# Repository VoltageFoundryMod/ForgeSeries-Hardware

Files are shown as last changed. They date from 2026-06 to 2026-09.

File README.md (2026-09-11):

# Voltage Foundry Modular

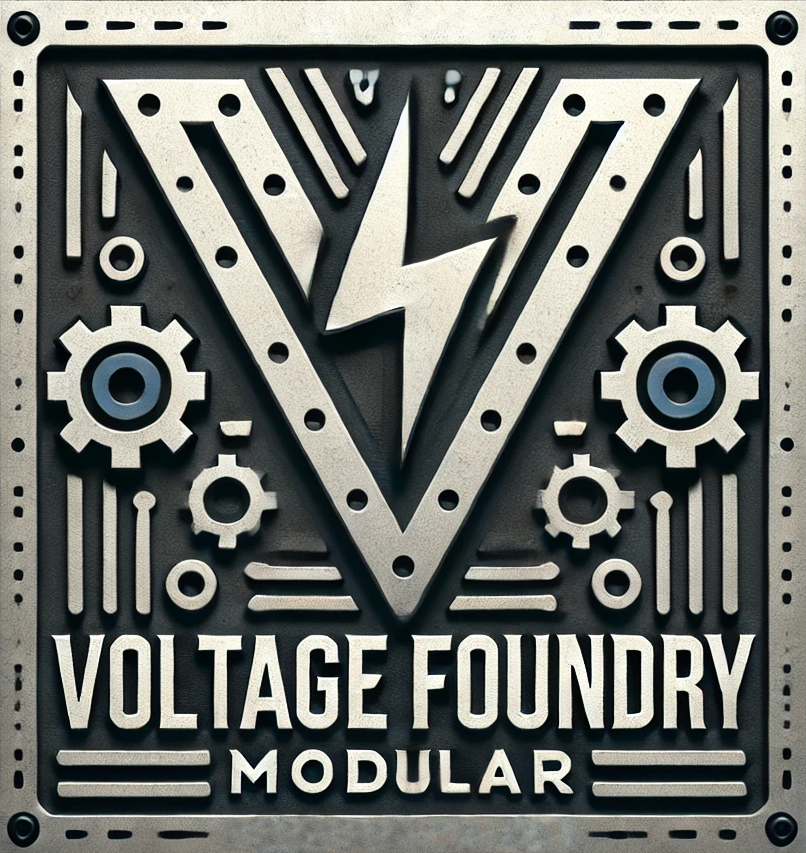
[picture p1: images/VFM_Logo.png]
Voltage Foundry Modular Logo


⚠️ I'm currently finishing a redesign of the hardware and will be ready soon, if you plan to build it, message me thru an issue. 
⚠️

This repository hosts the **Forge** series of modules for the Eurorack format. The **Forge** series is a collection of firmwares developed for the Forge V1 platform based on the Seeeduino Xiao and MCP4725 DAC and Forge V2 hardware based on the Seeeduino Xiao RP2040 anf the MCP4728 DAC.

The modules are designed to be easy to build and modify and be built with through-hole components. The firmware is based on the Arduino platform.

The concept is to have a generic hardware with a display, rotary encoder, trigger inputs and output, CV inputs and outputs allowing different modules by changing the firmware.

This project currently provides the following modules:

- [ClockForge](https://github.com/VoltageFoundryMod/ForgeSeries-CLK/) - A Clock Generator with multiple features like tap tempo, clock division, Euclidean rhythm and more.
- [NoteForge](https://github.com/VoltageFoundryMod/ForgeSeries-DQ/) - A Dual Quantizer with selectable scales and root notes for each channel, octave shift and envelopes.
- [ForgeView](https://github.com/VoltageFoundryMod/ForgeSeries-SCP/) - A scope visualizer with dual-trace, trigger and more.
- [GravityForge](https://github.com/VoltageFoundryMod/ForgeSeries-GEN/) - A generative sequencer with multiple features.

Modules can also be found on ModularGrid:

- [ClockForge](https://modulargrid.net/e/other-unknown-clockforge-by-voltage-foundry-modular)
- [NoteForge](https://modulargrid.net/e/other-unknown-NoteForge-by-voltage-foundry-modular)
- [ForgeView](https://modulargrid.net/e/other-unknown-forgeview-by-voltage-foundry-modular)
- [GravityForge](https://modulargrid.net/e/other-unknown-gravityforge-by-voltage-foundry-modular)

Each new module firmware will be in a separate folder which can be built and uploaded to the Seeeduino Xiao using PlatformIO.

## Production specifications

- Eurorack standard 3U 6HP size
- Power supply: 60mA
- Module depth: 42mm
- On-board converter from 12V to internal 5V

The module can be powered from the MCU USB port while in development mode and from Eurorack 5 pin when in calibration or use. **Do not power from both at the same time as this might damage the module**.

## Project State and Compatibility

- ✅ - Working
- ❎ - Not tested
- 🚧 - Under development
- ❓ - Works with issues

| Firmware | State | Remarks |
| --- | ----- | --- |
| ClockForge | ✅ | V1 HW with 1.x FW, V2 HW with 2.x FW |
| Dual Quantizer | ✅ | Only works on V1 hardware |
| Scope | ❓ | V1 HW, Spectrum Analyzer not working yet |
| Dual Sequencer | 🚧 | |
| Sequencer | ❎ | V1 HW, Original firmware, not tested |
| Generative Sequencer | ❎ | V1 HW, Original firmware, not tested |

## Hardware and PCB

### Hardware V2

### Hardware V1

For the PCBs, the module has one main circuit PCB, one control circuit PCB and one panel PCB. The files are available in the [gerbers](./Hardware/gerbers/) directory. There are files for the main board V1 and V2. The control board and panel are the same for both versions.

Check which Firmware is compatible with which hardware version in the table above before ordering the PCBs, as the main board V2 is only compatible with ClockForge 2.x firmware and not with the other firmwares as of now.

You can order them on any common PCB manufacturing service, I used [JLCPCB](https://jlcpcb.com/).

If the panel size is not correctly detected by JLC manually put 30x128.5 mm.

When ordering the display module, make sure to choose an 0.96 I2C oled module that has the pinout specified as GND-VCC-SCL-SDA as opposed to VCC-GND-SCL-SDA (both exist and the latter won't work).

Check each PCB version BOM for required components.

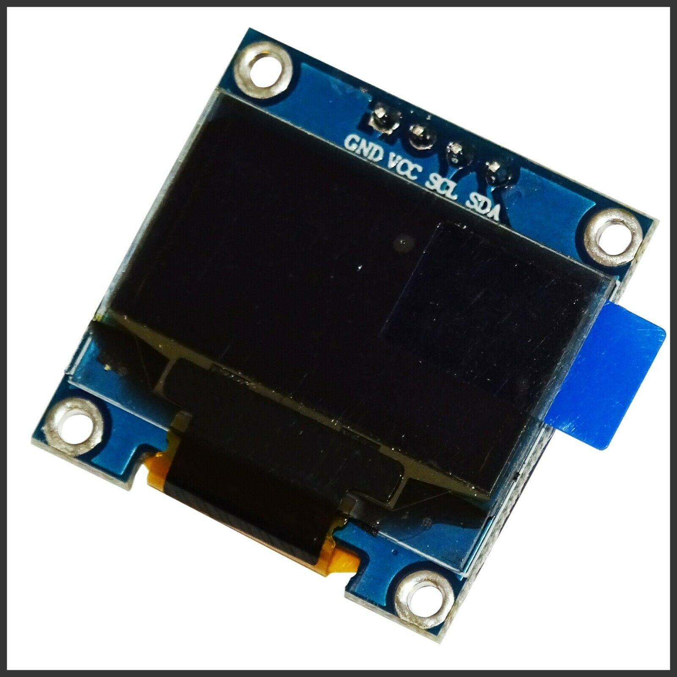
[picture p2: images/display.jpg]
Display Module


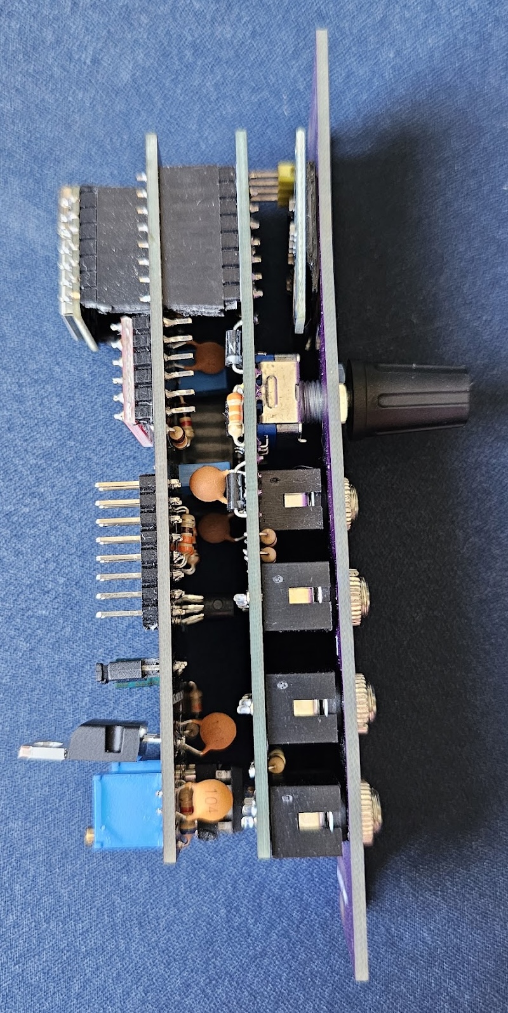
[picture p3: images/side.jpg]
Module Side


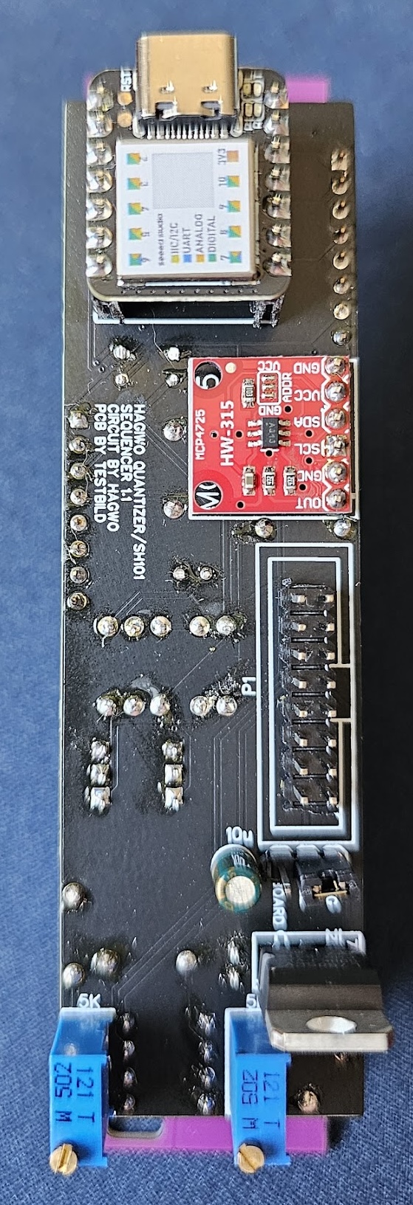
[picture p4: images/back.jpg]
Module Back


Output Diagram:

```text
|--------------------|
|                    |
|         O          |    1
|                    |
|   O           O    |  2   3
|                    |
|                    |
|   O           O    |  4   5
|                    |
|   O           O    |  6   7
|                    |
----------------------
```

- 1 - Trigger / Clock Input
- 2 - CV In 1
- 3 - CV In 2
- 4 - Digital Out 1
- 5 - Digital Out 2
- 6 - Analog Out 1 (Internal DAC)
- 7 - Analog Out 2 (External DAC)

or for the V2 main board:

- 1 - Trigger / Clock Input
- 2 - CV In 1
- 3 - CV In 2
- 4 - Analog Out 1
- 5 - Analog Out 2
- 6 - Analog Out 3
- 7 - Analog Out 4

## Expander header

The V2 main board has a 8 pin header for expanders. The pinout is as follows:

```text
|--------------------|
|                    |
|   1           2    |  VCC(3.3V)   SCL2
|                    |
|   3           4    |  VCC(OPAMP)  SDA2
|                    |
|   5           6    |  -10V(Ref)   GND
|                    |
|   7           8    |  GND         IN4
|                    |
----------------------
```

## Assembly

When assembling, you can either use a header for the screen or solder it directly, as it is a litte too tall.

## Calibration

The V2 board and 2.0 firmware have an internal calibration mode that allows you to set the input compensation and output gain without needing to do the calculations, so it should be easier to calibrate via it's menus. The output calibration still needs to be done by adjusting the trimmers, but the input compensation can be set in the menu and saved to EEPROM.

## Acknowledgements

The initial [hardware](./Hardware/) is based on Hagiwo 033 module. The quantizer base code is from the [original](https://note.com/solder_state/n/nb8b9a2f212a2) Hagiwo 033 Dual Quantizer and the updated thru-hole project by [Testbild-synth](https://github.com/Testbild-synth/HAGIWO-029-033-Eurorack-quantizer). Some ideas for the clock module were "taken" from the [LittleBen module](https://github.com/Quinienl/LittleBen-Firmware) from Quinie.nl and Pamela's Pro Workout.

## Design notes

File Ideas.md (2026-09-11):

# Ideas

Some ideas for projects, features, or improvements that could be implemented in the future. This document serves as a brainstorming space for potential enhancements and innovations.

- Create an output expander (Expander1) adding 4 more analog outputs with it's own DAC and OpAmp using the same I2C bus but on a different address. This would allow for a total of 6 analog outputs on the V2 board. Also expose the fourth ADC input on this board.
- Create an input expander (Expander2) allowing the user to have 8 inputs with an I2C ADC (define if that would be 4 potentiometers and 4 CV inputs or 8 CV inputs or a mix of those). This would allow for a total of 8 inputs on the V2 board. This would allow a more hands-on control to the modules.

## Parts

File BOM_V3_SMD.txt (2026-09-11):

Bill of Materials (BOM) for THT Components:

On Main Board:

1x Seeedstudio XIAO RP2040
2x 1x8 pin header for board interconnection
1x 2x5 pin header for power input
1x 2x4 pin header for expander module
2x 1x7 pin socket for Seeed Xiao board
4x 2k Vishay T93YA/Bourns 3296W vertical trimmer

Control Board:

1x Alps EC11 Rotary Encoder with push switch
2x 1x8 pin socket for board interconnection
7x Thonkiconn 3.5mm Jack
1x SSD1306 0.96" I2C OLED display module (with GND-VCC-SCL-SDA pinout)
4x 2mm Red LED
4x 470R 1/8w resistor
4x 39k 1/8 resistor
4x 10k 1/8 resistor
1x MCP6004 IC in DIP-14 package
1x 10u MLCC Ceramic Capacitor
1x 100n MLCC Ceramic Capacitor

Expander 1:

5x Thonkiconn 3.5mm Jack
1x 2x4 pin header for expander module
4x 2mm Red LED
4x 2k Vishay T93YA/Bourns 3296W vertical trimmer

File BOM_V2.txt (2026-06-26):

Bill of Materials (BOM):

On Main Board:

1x Seeedstudio XIAO RP2040
3x 100n Capacitor ceramic disc
3x 10u 25V Capacitor electrolytic radial
1x MCP4758 on breakout board (<https://pt.aliexpress.com/item/1005007635284632.html>)
1x Zener Diode 1N4734A
5x 470R Resistor
4x 6k8 Resistor
4x 10k Resistor
4x 5k adjustable trimmer (multi turn vertical)
1x MCP6004 DIP-14 op-amp
1x DIP-14 socket
1x 7805 Regulator TO-220

1x 3 pin header with Jumper for DAC power selection
2x 1x8 pin header and socket for board interconnection
1x 2x5 pin header for power input
1x 2x4 pin header for expander module
2x 1x7 pin socket for Seeed Xiao board

Control Board:

2x Resistor 330R
2x Resistor 470R or 2 Jumpers (resistor legs). See Obs below.
2x Resistor 3.3K
2x Resistor 18K
3x Resistor 33K
4x 10n Capacitor ceramic disc
6x BAT43 Diode
1x Alps EC11 Rotary Encoder with push switch
7x Thonkiconn 3.5mm Jack
1x SSD1306 0.96" I2C OLED display module (with GND-VCC-SCL-SDA pinout)

Common:

1x 3 pin header with Jumper for power selection
2x 1x8 pin header and socket for board interconnection
1x 2x8 pin header for power input
2x 1x7 pin socket for Seeed Xiao board

Obs for Main Boards V2:
If reusing existing control boards, replace the two 470R resistors (R13 and R20, close to bottom jacks) with a jumper as the new main board already includes them.
If building new control boards, just use a jumper wire in place of these two resistors.

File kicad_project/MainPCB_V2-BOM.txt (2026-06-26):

Bill of Materials (BOM):

2x 100n Capacitor ceramic disc
1x 10u 25V Capacitor electrolytic radial
1x MCP4758 on breakout board (<https://pt.aliexpress.com/item/1005007635284632.html>)
4x 470R Resistor
4x 6k8 Resistor
4x 10k Resistor
4x 5k adjustable trimmer (multi turn vertical)
1x MCP6004 DIP-14 op-amp
1x DIP-14 socket
1x 7805 Regulator TO-220

1x 3 pin header with Jumper for power selection
2x 1x8 pin header and socket for board interconnection
1x 2x8 pin header for power input
2x 1x7 pin socket for Seeed Xiao board

If using existing front (control) boards, replace the two 470R resistors (R13 and R20, close to bottom jacks) with a jumper as this new board already includes them.

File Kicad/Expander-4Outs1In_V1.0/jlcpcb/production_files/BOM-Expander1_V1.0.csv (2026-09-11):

Comment | Designator | Footprint | LCSC | Quantity
100 | R22 | R_0603 | C22775 | 1
100k | R20,R26,R28,R30,R32 | R_0603 | C25803 | 5
100n | C3,C4,C6 | C_0603 | C14663 | 3
100p | C15 | C_0603 | C14858 | 1
10k | R11,R13,R3,R5 | R_0603 | C25804 | 4
10u | C2,C5 | C_0805 | C15850 | 2
1n | C16 | C_0603 | C1588 | 1
200k | R19 | R_0603 | C25811 | 1
330 | R27,R29,R31,R33 | R_0603 | C23138 | 4
33k | R21 | R_0603 | C4216 | 1
33p | C18,C19,C20,C21 | C_0603 | C1663 | 4
470 | R10,R17,R18,R9 | R_0603 | C23179 | 4
6k8 | R12,R14,R4,R6 | R_0603 | C23212 | 4
9.1k | R15,R16,R7,R8 | R_0603 | C23260 | 4
BC847 | Q2,Q3,Q4,Q5 | SOT-23 | C8664 | 4
MCP4728A1 | U5 | MSOP-10_3x3mm_P0.5mm | C627342 | 1
MCP6001-OT | U2 | SOT-23-5 | C116490 | 1
MCP6004 | U1 | SOIC-14_3.9x8.7mm_P1.27mm | C7378 | 1

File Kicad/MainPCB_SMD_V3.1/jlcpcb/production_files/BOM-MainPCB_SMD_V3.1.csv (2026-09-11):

Comment | Designator | Footprint | LCSC | Quantity
1.5k | R17 | R_0805_2012Metric | C4310 | 1
100k | R18,R20,R22,R27 | R_0603 | C25803 | 4
100n | C1,C14,C15,C29,C3,C6,C9 | C_0603 | C14663 | 7
100p | C26,C27,C28 | C_0603 | C14858 | 3
10k | R1,R3,R5,R7 | R_0603 | C25804 | 4
10n | C30,C31 | C_0603 | C57112 | 2
10u | C13,C5 | C_0805 | C15850 | 2
10u | C12,C2,C4,C7,C8 | CP_Elec_4x5.4 | C3343 | 5
10uF | C25 | C_0603_1608Metric | C96446 | 1
1N4148WS | D1 | D_SOD-323 | C2128 | 1
1N5819WS | D6,D7 | D_SOD-323 | C191023 | 2
1n | C22,C23,C24 | C_0603 | C1588 | 3
2.2u | C17 | CP_Elec_4x5.4 | C43242 | 1
200k | R19,R21,R24 | R_0603 | C25811 | 3
220n | C10,C11,C16 | C_0603 | C21120 | 3
3.3k | R31,R32 | R_0603 | C22978 | 2
33k | R28,R29,R30 | R_0603 | C4216 | 3
33p | C18,C19,C20,C21 | C_0603 | C1663 | 4
4.7k | R23,R25,R26 | R_0603 | C23162 | 3
470 | R10,R11,R12,R9 | R_0603 | C23179 | 4
6k8 | R2,R4,R6,R8 | R_0603 | C23212 | 4
9.1k | R13,R14,R15,R16 | R_0603 | C23260 | 4
FerriteBead | FB1,FB2 | L_0805_2012Metric | C1015 | 2
L78L05 | U4 | SOT89-3 | C42738 | 1
L78M05CDT | U2 | TO-252-2 | C58069 | 1
LM4040LP-10 | U3 | SOT-23 | C201738 | 1
MCP1700x-300xxTT | U6 | SOT-23 | C39051 | 1
MCP4728A0 | U5 | MSOP-10_3x3mm_P0.5mm | C627341 | 1
MCP6004 | U1,U7 | SOIC-14_3.9x8.7mm_P1.27mm | C7378 | 2

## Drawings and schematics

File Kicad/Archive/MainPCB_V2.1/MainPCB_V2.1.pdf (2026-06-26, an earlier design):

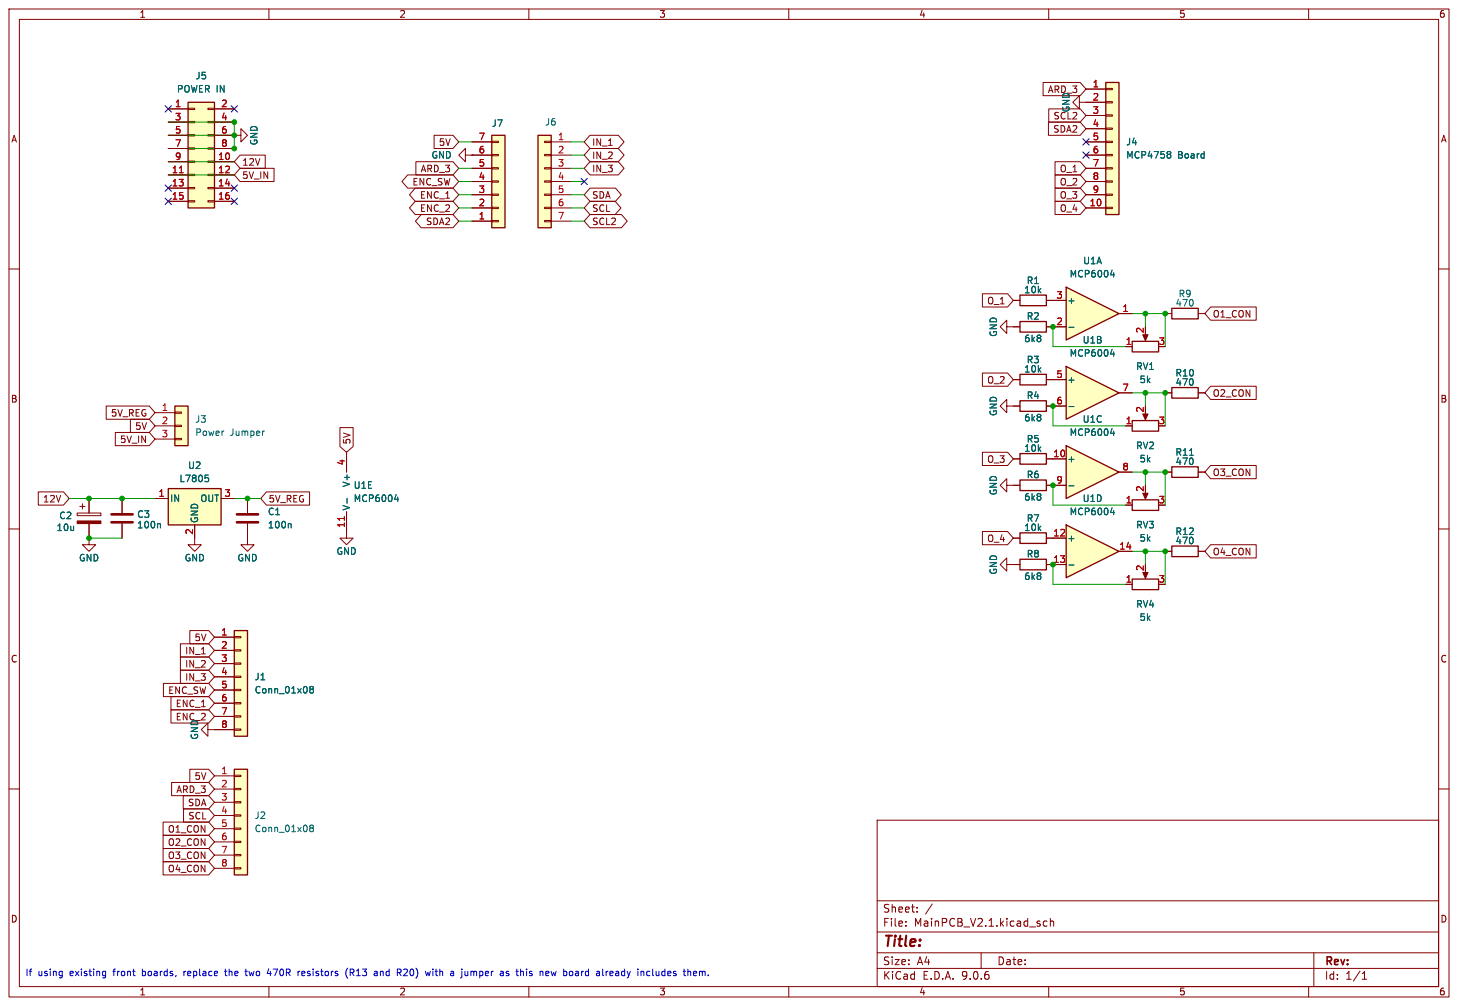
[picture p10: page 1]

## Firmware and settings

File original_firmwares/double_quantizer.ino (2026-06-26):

#include <FlashAsEEPROM_SAMD.h>//flash memory use as eeprom
//Display setting
#include <Adafruit_SSD1306.h>
#include <Adafruit_GFX.h>
#define OLED_ADDRESS 0x3C
#define SCREEN_WIDTH 128
#define SCREEN_HEIGHT 64
Adafruit_SSD1306 display(SCREEN_WIDTH, SCREEN_HEIGHT, &Wire, -1);
#include <Wire.h>
//Rotery encoder setting
#define  ENCODER_OPTIMIZE_INTERRUPTS //counter measure of noise
#include <Encoder.h>


#define ENC_PIN_1 3 //rotary encoder left pin
#define ENC_PIN_2 6 //rotary encoder right pin
#define CLK_PIN 7 //Clock input pin
#define CV_1_IN_PIN 8 // channel 1 analog in
#define CV_2_IN_PIN 9 // channel 2 analog in
#define ENC_CLICK_PIN 10 //pin for encoder switch
#define ENV_OUT_PIN_1 1
#define ENV_OUT_PIN_2 2

////////////////////////////////////////////
// ADC calibration. Change these according to your resistor values to make readings more accurate
float AD_CH1_calb = 0.98;//reduce resistance error
float AD_CH2_calb = 0.98;//reduce resistance error
/////////////////////////////////////////


Encoder myEnc(ENC_PIN_1, ENC_PIN_2);//rotery encoder library setting
float oldPosition  = -999;//rotery encoder library setting
float newPosition = -999;//rotery encoder library setting
int i = 1;

bool SW = 0;
bool old_SW = 0;
bool CLK_in = 0;
bool old_CLK_in = 0;
byte mode = 0; //0=select,1=atk1,2=dcy1,3=atk2,4=dcy2

float AD_CH1, old_AD_CH1, AD_CH2, old_AD_CH2;


int CV_in1, CV_in2;
float CV_out1, CV_out2, old_CV_out1, old_CV_out2;
long gate_timer1, gate_timer2; //EG curve progress speed

int cmp1, cmp2; //Detect closest note
int k = 0;

//envelope curve setting
int ad[200] = {//envelope table
 0, 15, 30, 44, 59, 73, 87, 101,  116,  130,  143,  157,  170,  183,  195,  208,  220,  233,  245,  257,  267,  279,  290,  302,  313,  324,  335,  346,  355,  366,  376,  386,  397,  405,  415,  425,  434,  443,  452,  462,  470,  479,  488,  495,  504,  513,  520,  528,  536,  544,  552,  559,  567,  573,  581,  589,  595,  602,  609,  616,  622,  629,  635,  642,  648,  654,  660,  666,  672,  677,  683,  689,  695,  700,  706,  711,  717,  722,  726,  732,  736,  741,  746,  751,  756,  760,  765,  770,  774,  778,  783,  787,  791,  796,  799,  803,  808,  811,  815,  818,  823,  826,  830,  834,  837,  840,  845,  848,  851,  854,  858,  861,  864,  866,  869,  873,  876,  879,  881,  885,  887,  890,  893,  896,  898,  901,  903,  906,  909,  911,  913,  916,  918,  920,  923,  925,  927,  929,  931,  933,  936,  938,  940,  942,  944,  946,  948,  950,  952,  954,  955,  957,  960,  961,  963,  965,  966,  968,  969,  971,  973,  975,  976,  977,  979,  980,  981,  983,  984,  986,  988,  989,  990,  991,  993,  994,  995,  996,  997,  999,  1000, 1002, 1003, 1004, 1005, 1006, 1007, 1008, 1009, 1010, 1012, 1013, 1014, 1014, 1015, 1016, 1017, 1018, 1019, 1020
};
int ad1 = 0;//PWM DUTY reference
int ad2 = 0;//PWM DUTY reference
bool ad_trg1 = 0;
bool ad_trg2 = 0;
int atk1, atk2, dcy1, dcy2; //attack time,decay time
bool sync1, sync2; //0=sync with trig , 1=sync with note change
int sensitivity_ch1, sensitivity_ch2, oct1, oct2; //sens = AD input attn,amp.oct=octave shift

//CV setting
int cv_qnt_thr_buf1[62];//input quantize
int cv_qnt_thr_buf2[62];//input quantize
byte search_qnt = 0;
bool note1[12];//1=note valid,0=note invalid
bool note2[12];
byte note_str1, note_str11, note_str2, note_str22;

//display
bool disp_reflesh = 1;//0=not reflesh display , 1= reflesh display , countermeasure of display reflesh bussy

//-------------------------------Initial setting--------------------------
void setup() {
 analogWriteResolution(10);
 analogReadResolution(12);
 pinMode(CLK_PIN, INPUT_PULLDOWN); //CLK in
 pinMode(CV_1_IN_PIN, INPUT);//IN1
 pinMode(CV_2_IN_PIN, INPUT);//IN2
 pinMode(ENC_CLICK_PIN, INPUT_PULLUP);//push sw
 pinMode(ENV_OUT_PIN_1, OUTPUT); //CH1 EG out
 pinMode(ENV_OUT_PIN_2, OUTPUT); //CH2 EG out
 // OLED initialize
 display.begin(SSD1306_SWITCHCAPVCC, 0x3C);
 display.clearDisplay();

 //I2C connect
 Wire.begin();

 // ADC settings. These increase ADC reading stability but at the cost of cycle time. Takes around 0.7ms for one reading with these
 REG_ADC_AVGCTRL |= ADC_AVGCTRL_SAMPLENUM_1;
 ADC->AVGCTRL.reg = ADC_AVGCTRL_SAMPLENUM_128 | ADC_AVGCTRL_ADJRES(4);


 //read stored data
 if (EEPROM.isValid() == 1) { //already writed eeprom
   note_str1 = EEPROM.read(1);
   note_str11 = EEPROM.read(2);
   note_str2 = EEPROM.read(3);
   note_str22 = EEPROM.read(4);
   atk1 = EEPROM.read(5);
   dcy1 = EEPROM.read(6);
   atk2 = EEPROM.read(7);
   dcy2 = EEPROM.read(8);
   sync1 = EEPROM.read(9);
   sync2 = EEPROM.read(10);
   oct1 = EEPROM.read(11);
   oct2 = EEPROM.read(12);
   sensitivity_ch1 = EEPROM.read(13);
   sensitivity_ch2 = EEPROM.read(14);
 }
 else if ( EEPROM.isValid() == 0) { //no eeprom data , setting any number to eeprom
   note_str1 = 0;
   note_str11 = 0;
   note_str2 = 2;
   note_str22 = 2;
   atk1 = 1;
   dcy1 = 4;
   atk2 = 2;
   dcy2 = 6;
   sync1 = 1;
   sync2 = 1;
   oct1 = 2;
   oct2 = 2;
   sensitivity_ch1 = 4;
   sensitivity_ch2 = 4;
 }
 //setting stored note data
 for ( int j = 0; j <= 7 ; j++ ) {
   note1[j] = bitRead(note_str1, j);
   note2[j] = bitRead(note_str2, j);
 }
 for ( int j = 0; j <= 3 ; j++ ) {
   note1[j + 8] = bitRead(note_str11, j);
   note2[j + 8] = bitRead(note_str22, j);
 }

 //initial quantizer setting
 k = 0;
 for (byte j = 0; j <= 62; j++) {
   if (note1[j % 12] == 1) {
     cv_qnt_thr_buf1[k] = 17 * j - 8;
     k++;
   }
 }
 k = 0;
 for (byte j = 0; j <= 62; j++) {
   if (note2[j % 12] == 1) {
     cv_qnt_thr_buf2[k] = 17 * j - 8;
     k++;
   }
 }
}

void loop() {
 old_SW = SW;
 old_CLK_in = CLK_in;
 old_CV_out1 = CV_out1;
 old_CV_out2 = CV_out2;
 old_AD_CH1 = AD_CH1;
 old_AD_CH2 = AD_CH2;

 //-------------------------------Rotery endoder--------------------------
 newPosition = myEnc.read();
 if ( (newPosition - 3) / 4  > oldPosition / 4) { //4 is resolution of encoder
   oldPosition = newPosition;
   disp_reflesh = 1;
   switch (mode) {
     case 0:
       i = i - 1;
       if (i < 0) {
         i = 34;
       }
       break;
     case 1:
       atk1--;
       break;
     case 2:
       dcy1--;
       break;
     case 3:
       atk2--;
       break;
     case 4:
       dcy2--;
       break;
   }
 }
 else if ( (newPosition + 3) / 4  < oldPosition / 4 ) { //4 is resolution of encoder
   oldPosition = newPosition;
   disp_reflesh = 1;
   switch (mode) {
     case 0:
       i = i + 1;
       if (34 < i) {
         i = 0;
       }
       break;
     case 1:
       atk1++;
       break;
     case 2:
       dcy1++;
       break;
     case 3:
       atk2++;
       break;
     case 4:
       dcy2++;
       break;
   }
 }
 i = constrain(i, 0, 34);
 atk1 = constrain(atk1, 1, 26);
 dcy1 = constrain(dcy1, 1, 26);
 atk2 = constrain(atk2, 1, 26);
 atk2 = constrain(atk2, 1, 26);
 dcy2 = constrain(dcy2, 1, 26);

 //-----------------PUSH SW------------------------------------
 SW = digitalRead(ENC_CLICK_PIN);
 if (SW == 1 && old_SW != 1) {
   disp_reflesh = 1;
   if (i <= 11 && i >= 0 && mode == 0) {
     note1[i] = !note1[i];
   }
   else if (i >= 14 && i <= 25 && mode == 0) {
     note2[i - 14] = !note2[i - 14];
   }
   else if (i == 12 && mode == 0) { //CH1 atk setting
     mode = 1;//atk1 setting
   }
   else if (i == 12 && mode == 1) { //CH1 atk setting
     mode = 0;
   }
   else if (i == 13 && mode == 0) { //CH1 atk setting
     mode = 2;//dcy1 setting
   }
   else if (i == 13 && mode == 2) { //CH1 atk setting
     mode = 0;
   }
   else if (i == 26 && mode == 0) { //CH1 atk setting
     mode = 3;//atk2 setting
   }
   else if (i == 26 && mode == 3) { //CH1 atk setting
     mode = 0;
   }
   else if (i == 27 && mode == 0) { //CH1 atk setting
     mode = 4;//dcy2 setting
   }
   else if (i == 27 && mode == 4) { //CH1 atk setting
     mode = 0;
   }
   else if (i == 28) { //CH1 sync setting
     sync1 = !sync1;
   }
   else if (i == 29) { //CH2 sync setting
     sync2 = !sync2;
   }
   else if (i == 30) { //CH1 oct setting
     oct1++;
     if (oct1 > 4) {
       oct1 = 0;
     }
   }
   else if (i == 31) { //CH2 oct setting
     oct2++;
     if (oct2 > 4) {
       oct2 = 0;
     }
   }
   else if (i == 32) { //CH1 sens setting
     sensitivity_ch1++;
     if (sensitivity_ch1 > 8) {
       sensitivity_ch1 = 0;
     }
   }
   else if (i == 33) { //CH2 sens setting
     sensitivity_ch2++;
     if (sensitivity_ch2 > 8) {
       sensitivity_ch2 = 0;
     }
   }
   else if (i == 34) { //CH1 sync setting
     save();
   }

   //select note set
   k = 0;
   for (byte j = 0; j <= 62; j++) {
     if (note1[j % 12] == 1) {
       cv_qnt_thr_buf1[k] = 17 * j - 8;
       k++;
     }
   }
   k = 0;
   for (byte j = 0; j <= 62; j++) {
     if (note2[j % 12] == 1) {
       cv_qnt_thr_buf2[k] = 17 * j - 8;
       k++;
     }
   }
 }

 //-------------------------------Analog read and qnt setting--------------------------
 AD_CH1 = analogRead(CV_1_IN_PIN) / AD_CH1_calb; 
 AD_CH1 = AD_CH1 * (16 + sensitivity_ch1) / 20; //sens setting
  if(AD_CH1 > 4095){
   AD_CH1 = 4095;
 }
  for ( search_qnt = 0; search_qnt <= 61 ; search_qnt++ ) {// quantize
     if ( AD_CH1 >= cv_qnt_thr_buf1[search_qnt]*4 && AD_CH1 < cv_qnt_thr_buf1[search_qnt + 1]*4) {
       cmp1 = AD_CH1 - cv_qnt_thr_buf1[search_qnt]*4;//Detect closest note
       cmp2 = cv_qnt_thr_buf1[search_qnt + 1]*4 - AD_CH1;//Detect closest note
       break;
     }
   }
   if (cmp1 >= cmp2) {//Detect closest note
     CV_out1 = (cv_qnt_thr_buf1[search_qnt + 1] + 8) / 17 * 68.25 + (oct1 - 2) * 12 * 68.25;
     CV_out1 = constrain(CV_out1, 0, 4095);
   }
   else if (cmp2 > cmp1) {//Detect closest note
     CV_out1 = (cv_qnt_thr_buf1[search_qnt] + 8) / 17 * 68.25 + (oct1 - 2) * 12 * 68.25;
     CV_out1 = constrain(CV_out1, 0, 4095);
   }
 AD_CH2 = analogRead(CV_2_IN_PIN) / AD_CH2_calb; //12bit to 10bit
 AD_CH2 = AD_CH2 * (16 + sensitivity_ch2) / 20; //sens setting
  if(AD_CH2 > 4095){
   AD_CH2 = 4095;
 }
   for ( search_qnt = 0; search_qnt <= 61 ; search_qnt++ ) {// quantize
     if ( AD_CH2 >= cv_qnt_thr_buf2[search_qnt]*4 && AD_CH2 < cv_qnt_thr_buf2[search_qnt + 1]*4) {
       cmp1 = AD_CH2 - cv_qnt_thr_buf1[search_qnt]*4;
       cmp2 = cv_qnt_thr_buf1[search_qnt + 1]*4 - AD_CH2;
       break;
     }
   }
   if (cmp1 >= cmp2) {
     CV_out2 = (cv_qnt_thr_buf2[search_qnt + 1] + 8) / 17 * 68.25 + (oct2 - 2) * 12 * 68.25;
     CV_out2 = constrain(CV_out2, 0, 4095);
   }
   else if (cmp2 > cmp1) {
     CV_out2 = (cv_qnt_thr_buf2[search_qnt] + 8) / 17 * 68.25 + (oct2 - 2) * 12 * 68.25;
     CV_out2 = constrain(CV_out2, 0, 4095);
   }
 
 //-------------------------------OUTPUT SETTING--------------------------
 CLK_in = digitalRead(CLK_PIN);

 //trig sync trigger detect
 if (CLK_in == 1 && old_CLK_in == 0) {
   if (sync1 == 0) {
     ad1 = 0;
     ad_trg1 = 1;
     gate_timer1 = micros();
     if (atk1 == 1) {
       ad1 = 200; //no attack time
     }
   }
   if (sync2 == 0)
     ad2 = 0;
   ad_trg2 = 1;
   gate_timer2 = micros();
   if (atk2 == 1) {
     ad2 = 200; //no attack time
   }
 }

 //note sync trigger detect
 if (sync1 == 1 && old_CV_out1 != CV_out1) {
   ad1 = 0;
   ad_trg1 = 1;
   gate_timer1 = micros();
   if (atk1 == 1) {
     ad1 = 200; //no attack time
   }
 }
 if (sync2 == 1 && old_CV_out2 != CV_out2) {
   ad2 = 0;
   ad_trg2 = 1;
   gate_timer2 = micros();
   if (atk2 == 1) {
     ad2 = 200; //no attack time
   }
 }

 //envelope ch1 out
 if ( gate_timer1 + (atk1 - 1) * 200 <= micros() && ad_trg1 == 1 && ad1 <= 199) {
   ad1++;
   gate_timer1 = micros();
 }
 else if ( gate_timer1 + (dcy1 - 1) * 600 <= micros() && ad_trg1 == 1 && ad1 > 199) {
   ad1++;
   gate_timer1 = micros();
 }

 if (ad1 <= 199) {
   PWM1(1021 - ad[ad1]);
 }
 else if (ad1 > 199 && ad1 < 399) {
   PWM1(ad[ad1 - 200]);
 }
 else  if (ad1 >= 399) {
   PWM1(1023);
   ad_trg1 = 0;
 }

 //envelope ch2 out
 if ( gate_timer2 + (atk2 - 1) * 200 <= micros() && ad_trg2 == 1 && ad2 <= 199) {
   ad2++;
   gate_timer2 = micros();
 }
 else if ( gate_timer2 + (dcy2 - 1) * 600 <= micros() && ad_trg2 == 1 && ad2 > 199) {
   ad2++;
   gate_timer2 = micros();
 }

 if (ad2 <= 199) {
   PWM2(1021 - ad[ad2]);
 }
 else if (ad2 > 199 && ad2 < 399) {
   PWM2(ad[ad2 - 200]);
 }
 else  if (ad2 >= 399) {
   PWM2(1023);
   ad_trg2 = 0;
 }

 //DAC OUT
 if (old_CV_out1 != CV_out1) {
   intDAC(CV_out1);
 }
 if (old_CV_out2 != CV_out2) {
   MCP(CV_out2);
 }

 //display out
 if (disp_reflesh == 1) {
   OLED_display();//reflesh display
   disp_reflesh = 0;
 }
}


//-----------------------------DISPLAY----------------------------------------
void OLED_display() {
 display.clearDisplay();
 display.setTextSize(1);
 display.setTextColor(WHITE);

 if (i <= 27) {
   if (note1[1] == 0) {
     display.drawRoundRect(7, 0, 11, 13, 2, WHITE);
   }
   else if (note1[1] == 1) {
     display.fillRoundRect(7, 0, 11, 13, 2, WHITE);
   }

   if (note1[3] == 0) {
     display.drawRoundRect(7 + 14 * 1, 0, 11, 13, 2, WHITE);
   }
   else if (note1[3] == 1) {
     display.fillRoundRect(7 + 14 * 1, 0, 11, 13, 2, WHITE);
   }

   if (note1[6] == 0) {
     display.drawRoundRect(8 + 14 * 3, 0, 11, 13, 2, WHITE);
   }
   else if (note1[6] == 1) {
     display.fillRoundRect(8 + 14 * 3, 0, 11, 13, 2, WHITE);
   }
   if (note1[8] == 0) {
     display.drawRoundRect(8 + 14 * 4, 0, 11, 13, 2, WHITE);
   }
   else if (note1[8] == 1) {
     display.fillRoundRect(8 + 14 * 4, 0, 11, 13, 2, WHITE);
   }
   if (note1[10] == 0) {
     display.drawRoundRect(8 + 14 * 5, 0, 11, 13, 2, WHITE);
   }
   else if (note1[10] == 1) {
     display.fillRoundRect(8 + 14 * 5, 0, 11, 13, 2, WHITE);
   }
   if (note1[0] == 0) {
     display.drawRoundRect(0, 15, 11, 13, 2, WHITE);
   }
   else if (note1[0] == 1) {
     display.fillRoundRect(0, 15, 11, 13, 2, WHITE);
   }
   if (note1[2] == 0) {
     display.drawRoundRect(0 + 14 * 1, 15, 11, 13, 2, WHITE);
   }
   else if (note1[2] == 1) {
     display.fillRoundRect(0 + 14 * 1, 15, 11, 13, 2, WHITE);
   }
   if (note1[4] == 0) {
     display.drawRoundRect(0 + 14 * 2, 15, 11, 13, 2, WHITE);
   }
   else if (note1[4] == 1) {
     display.fillRoundRect(0 + 14 * 2, 15, 11, 13, 2, WHITE);
   }
   if (note1[5] == 0) {
     display.drawRoundRect(0 + 14 * 3, 15, 11, 13, 2, WHITE);
   }
   else if (note1[5] == 1) {
     display.fillRoundRect(0 + 14 * 3, 15, 11, 13, 2, WHITE);
   }
   if (note1[7] == 0) {
     display.drawRoundRect(0 + 14 * 4, 15, 11, 13, 2, WHITE);
   }
   else if (note1[7] == 1) {
     display.fillRoundRect(0 + 14 * 4, 15, 11, 13, 2, WHITE);
   }
   if (note1[9] == 0) {
     display.drawRoundRect(0 + 14 * 5, 15, 11, 13, 2, WHITE);
   }
   else if (note1[9] == 1) {
     display.fillRoundRect(0 + 14 * 5, 15, 11, 13, 2, WHITE);
   }
   if (note1[11] == 0) {
     display.drawRoundRect(0 + 14 * 6, 15, 11, 13, 2, WHITE);
   }
   else if (note1[11] == 1) {
     display.fillRoundRect(0 + 14 * 6, 15, 11, 13, 2, WHITE);
   }


   if (note2[1] == 0) {
     display.drawRoundRect(7, 0 + 34, 11, 13, 2, WHITE);
   }
   else if (note2[1] == 1) {
     display.fillRoundRect(7, 0 + 34, 11, 13, 2, WHITE);
   }

   if (note2[3] == 0) {
     display.drawRoundRect(7 + 14 * 1, 0 + 34, 11, 13, 2, WHITE);
   }
   else if (note2[3] == 1) {
     display.fillRoundRect(7 + 14 * 1, 0 + 34, 11, 13, 2, WHITE);
   }

   if (note2[6] == 0) {
     display.drawRoundRect(8 + 14 * 3, 0 + 34, 11, 13, 2, WHITE);
   }
   else if (note2[6] == 1) {
     display.fillRoundRect(8 + 14 * 3, 0 + 34, 11, 13, 2, WHITE);
   }
   if (note2[8] == 0) {
     display.drawRoundRect(8 + 14 * 4, 0 + 34, 11, 13, 2, WHITE);
   }
   else if (note2[8] == 1) {
     display.fillRoundRect(8 + 14 * 4, 0 + 34, 11, 13, 2, WHITE);
   }
   if (note2[10] == 0) {
     display.drawRoundRect(8 + 14 * 5, 0 + 34, 11, 13, 2, WHITE);
   }
   else if (note2[10] == 1) {
     display.fillRoundRect(8 + 14 * 5, 0 + 34, 11, 13, 2, WHITE);
   }
   if (note2[0] == 0) {
     display.drawRoundRect(0, 15 + 34, 11, 13, 2, WHITE);
   }
   else if (note2[0] == 1) {
     display.fillRoundRect(0, 15 + 34, 11, 13, 2, WHITE);
   }
   if (note2[2] == 0) {
     display.drawRoundRect(0 + 14 * 1, 15 + 34, 11, 13, 2, WHITE);
   }
   else if (note2[2] == 1) {
     display.fillRoundRect(0 + 14 * 1, 15 + 34, 11, 13, 2, WHITE);
   }
   if (note2[4] == 0) {
     display.drawRoundRect(0 + 14 * 2, 15 + 34, 11, 13, 2, WHITE);
   }
   else if (note2[4] == 1) {
     display.fillRoundRect(0 + 14 * 2, 15 + 34, 11, 13, 2, WHITE);
   }
   if (note2[5] == 0) {
     display.drawRoundRect(0 + 14 * 3, 15 + 34, 11, 13, 2, WHITE);
   }
   else if (note2[5] == 1) {
     display.fillRoundRect(0 + 14 * 3, 15 + 34, 11, 13, 2, WHITE);
   }
   if (note2[7] == 0) {
     display.drawRoundRect(0 + 14 * 4, 15 + 34, 11, 13, 2, WHITE);
   }
   else if (note2[7] == 1) {
     display.fillRoundRect(0 + 14 * 4, 15 + 34, 11, 13, 2, WHITE);
   }
   if (note2[9] == 0) {
     display.drawRoundRect(0 + 14 * 5, 15 + 34, 11, 13, 2, WHITE);
   }
   else if (note2[9] == 1) {
     display.fillRoundRect(0 + 14 * 5, 15 + 34, 11, 13, 2, WHITE);
   }
   if (note2[11] == 0) {
     display.drawRoundRect(0 + 14 * 6, 15 + 34, 11, 13, 2, WHITE);
   }
   else if (note2[11] == 1) {
     display.fillRoundRect(0 + 14 * 6, 15 + 34, 11, 13, 2, WHITE);
   }


   //draw triangle
   if (i <= 4) {
     display.fillTriangle(5 + i * 7, 28, 2 + i * 7, 33, 8 + i * 7, 33, WHITE);
   }
   else if (i >= 5 && i <= 11) {
     display.fillTriangle(12 + i * 7, 28, 9 + i * 7, 33, 15 + i * 7, 33, WHITE);
   }
   else if (i == 12 && mode == 0) {
     display.drawTriangle(127, 0, 127, 6, 121, 3, WHITE);
   }
   else if (i == 12 && mode == 1) {
     display.fillTriangle(127, 0, 127, 6, 121, 3, WHITE);
   }
   else if (i == 13 && mode == 0) {
     display.drawTriangle(127, 16, 127, 22, 121, 19, WHITE);
   }
   else if (i == 13 && mode == 2) {
     display.fillTriangle(127, 16, 127, 22, 121, 19, WHITE);
   }
   else if (i >= 14 && i <= 18) {
     display.fillTriangle(12 + (i - 15) * 7, 33, 9 + (i - 15) * 7, 28, 15 + (i - 15) * 7, 28, WHITE);
   }
   else if (i >= 19 && i <= 25) {
     display.fillTriangle(12 + (i - 14) * 7, 33, 9 + (i - 14) * 7, 28, 15 + (i - 14) * 7, 28, WHITE);
   }
   else if (i == 26 && mode == 0) {
     display.drawTriangle(127, 32, 127, 38, 121, 35, WHITE);
   }
   else if (i == 26 && mode == 3) {
     display.fillTriangle(127, 32, 127, 38, 121, 35, WHITE);
   }
   else if (i == 27 && mode == 0) {
     display.drawTriangle(127, 48, 127, 54, 121, 51, WHITE);
   }
   else if (i == 27 && mode == 4) {
     display.fillTriangle(127, 48, 127, 54, 121, 51, WHITE);
   }

   //draw envelope param
   display.setTextSize(1);
   display.setCursor(100, 0);//effect param3
   display.print("ATK");
   display.setCursor(100, 16);//effect param3
   display.print("DCY");
   display.setCursor(100, 32);//effect param3
   display.print("ATK");
   display.setCursor(100, 48);//effect param3
   display.print("DCY");
   display.fillRoundRect(100, 9, atk1 + 1, 4, 1, WHITE);
   display.fillRoundRect(100, 25, dcy1 + 1, 4, 1, WHITE);
   display.fillRoundRect(100, 41, atk2 + 1, 4, 1, WHITE);
   display.fillRoundRect(100, 57, dcy2 + 1, 4, 1, WHITE);
 }

 //draw config setting
 if (i >= 28) {  //draw sync mode setting
   display.setTextSize(1);
   display.setCursor(10, 0);
   display.print("SYNC CH1:");
   display.setCursor(72, 0);
   if (sync1 == 0) {
     display.print("TRIG");
   }
   else if (sync1 == 1) {
     display.print("NOTE");
   }
   display.setCursor(10, 9);
   display.print("     CH2:");
   display.setCursor(72, 9);
   if (sync2 == 0) {
     display.print("TRIG");
   }
   else if (sync2 == 1) {
     display.print("NOTE");
   }

   display.setCursor(10, 18);    //draw octave shift
   display.print("OCT  CH1:");
   display.setCursor(10, 27);
   display.print("     CH2:");
   display.setCursor(72, 18);
   display.print(oct1 - 2);
   display.setCursor(72, 27);
   display.print(oct2 - 2);

   display.setCursor(10, 36);    //draw sensitivity
   display.print("SENS CH1:");
   display.setCursor(10, 45);
   display.print("     CH2:");
   display.setCursor(72, 36);
   display.print(sensitivity_ch1 - 4);
   display.setCursor(72, 45);
   display.print(sensitivity_ch2 - 4);

   display.setCursor(10, 54);//draw save
   display.print("SAVE");

   display.drawTriangle(0, 0 + (i - 28) * 9, 0, 6 + (i - 28) * 9, 7, 3 + (i - 28) * 9, WHITE);
 }
 display.display();
}

//-----------------------------OUTPUT----------------------------------------
void intDAC(int intDAC_OUT) {
 analogWrite(A0, intDAC_OUT / 4); // "/4" -> 12bit to 10bit
}

void MCP(int MCP_OUT) {
 Wire.beginTransmission(0x60);
 Wire.write((MCP_OUT >> 8) & 0x0F);
 Wire.write(MCP_OUT);
 Wire.endTransmission();
}

void PWM1(int duty1) {
 pwm(ENV_OUT_PIN_1, 46000, duty1);
}
void PWM2(int duty2) {
 pwm(ENV_OUT_PIN_2, 46000,  duty2);
}

//-----------------------------store data----------------------------------------
void save() {//save setting data to flash memory
 delay(100);
 for ( int j = 0; j <= 7 ; j++ ) {//Convert note setting to bits
   bitWrite(note_str1, j, note1[j]);
   bitWrite(note_str2, j, note2[j]);
 }
 for ( int j = 0; j <= 3 ; j++ ) {
   bitWrite(note_str11, j, note1[j + 8]);
   bitWrite(note_str22, j, note2[j + 8]);
 }

 EEPROM.write(1, note_str1);//ch1 select note
 EEPROM.write(2, note_str11);//ch1 select note
 EEPROM.write(3, note_str2);//ch2 select note
 EEPROM.write(4, note_str22);//ch2 select note
 EEPROM.write(5, atk1);
 EEPROM.write(6, dcy1);
 EEPROM.write(7, atk2);
 EEPROM.write(8, dcy2);
 EEPROM.write(9, sync1);
 EEPROM.write(10, sync2);
 EEPROM.write(11, oct1);
 EEPROM.write(12, oct2);
 EEPROM.write(13, sensitivity_ch1);
 EEPROM.write(14, sensitivity_ch2);
 EEPROM.commit();
 display.clearDisplay();  // clear display
 display.setTextSize(1);
 display.setTextColor(BLACK, WHITE);
 display.setCursor(10, 54);
 display.print("SAVEED");
 display.display();
 delay(1000);
}

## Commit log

2026-06-26 Move hardware files to own repository
    [BOM-Control_PCB_v1.2.csv, BOM-MainPCB_V2.2.csv, Control_PCB_v1.2.kicad_pcb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]
2026-09-11 Update with latest PCB Revisions
    [BOM-ControlPCB_SMD_V3.1.csv, BOM-Control_PCB_v1.2.csv, BOM-Expander1_V1.0.csv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]
2026-09-11 Update kicad model dir
    [ControlPCB_SMD_V3.0.kicad_pcb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]
